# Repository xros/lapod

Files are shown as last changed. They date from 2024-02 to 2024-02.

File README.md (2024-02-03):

# LaPOD
LaPOD is a project to create a logic analyzer probe for the various [Rigol]
oscilloscopes that feature the logic analyzer connector. Not all scopes have
the connector exposed and not all scopes have the components needed on the
PCB. But for those that do, the LaPOD could be a cheap alternative to get
those probes.

## Scope support
Currently supported is the MSO5000 series, which feature a 50 pin IDC connector
and the DHO900, which features the same 50 pin connector, but is a bit more
narrow at the front. To cater for either needs or choice, there's two breakout
boards that feature either a full, but wider HDMI connector, or a mini HDMI
connector which makes the PCB as narrow as possible.

The idea is, to also get a 68 pin IDC connector added, but that requires
the knowledge of the pinout and someone that can validate and test the design.
The 68 pin IDC connector should have nearly the same signals however and would
fit the DS1074Z-S Plus for example.

The DS7000 and MSO8000 feature a PCI express 1x connector (34 pins), with an
unknown pinout, but the idea is that it could very much also support our pods.

## PODs
Currently, there are 3 pods available. The LMH7322 based pod, where two dual
channel chips supply 4 bits to the pod. The LMH7322 is the same chip used in
the official PLA2216 (MSO5000) and RPL1116 (DS1000Z) probes. It may also be
used on the RPL2316 (DS2000, DS7000 and MSO8000). The original probe needs 8
of these chips for 16 channels, and that brings the cost of the chips alone
up to around $75. Probably one of the reason of the high price.

Then there's also the LMH7324 based pod. Here a single quad channel chip is
used to supply the 4 bits to the pod. The LMH7324 is very closely related to
the LMH7322, but not identical. It is a little bit cheaper option and for some
signal scenarios even preferred to have the same chip handle 4 channels.

Finally, there is the SNV65LVDS based chip. It is a much cheaper chip that can
do logic signal detection, but at a very much more limited range. It also costs
considerably less. A true cheap alternative.

## Outputs
The schematics, PCB's gerbers etc are generated by the CI pipeline and can be
found under [releases](https://gitlab.com/riglol/lapod/-/releases) for tagged
builds. Tagging happens after verification however, so the release-candidates,
the files sent out to the board house for verification can be found under
[packages](https://gitlab.com/riglol/lapod/-/packages).

## Contact
Discussion about the development of these pods is held over on the
[EEVBlog forum].

[Rigol]: https://rigolna.com
[EEVBlog forum]: https://www.eevblog.com/forum/testgear/another-low-cost-la-probe-for-rigol-mso5000-by-oliv3r/

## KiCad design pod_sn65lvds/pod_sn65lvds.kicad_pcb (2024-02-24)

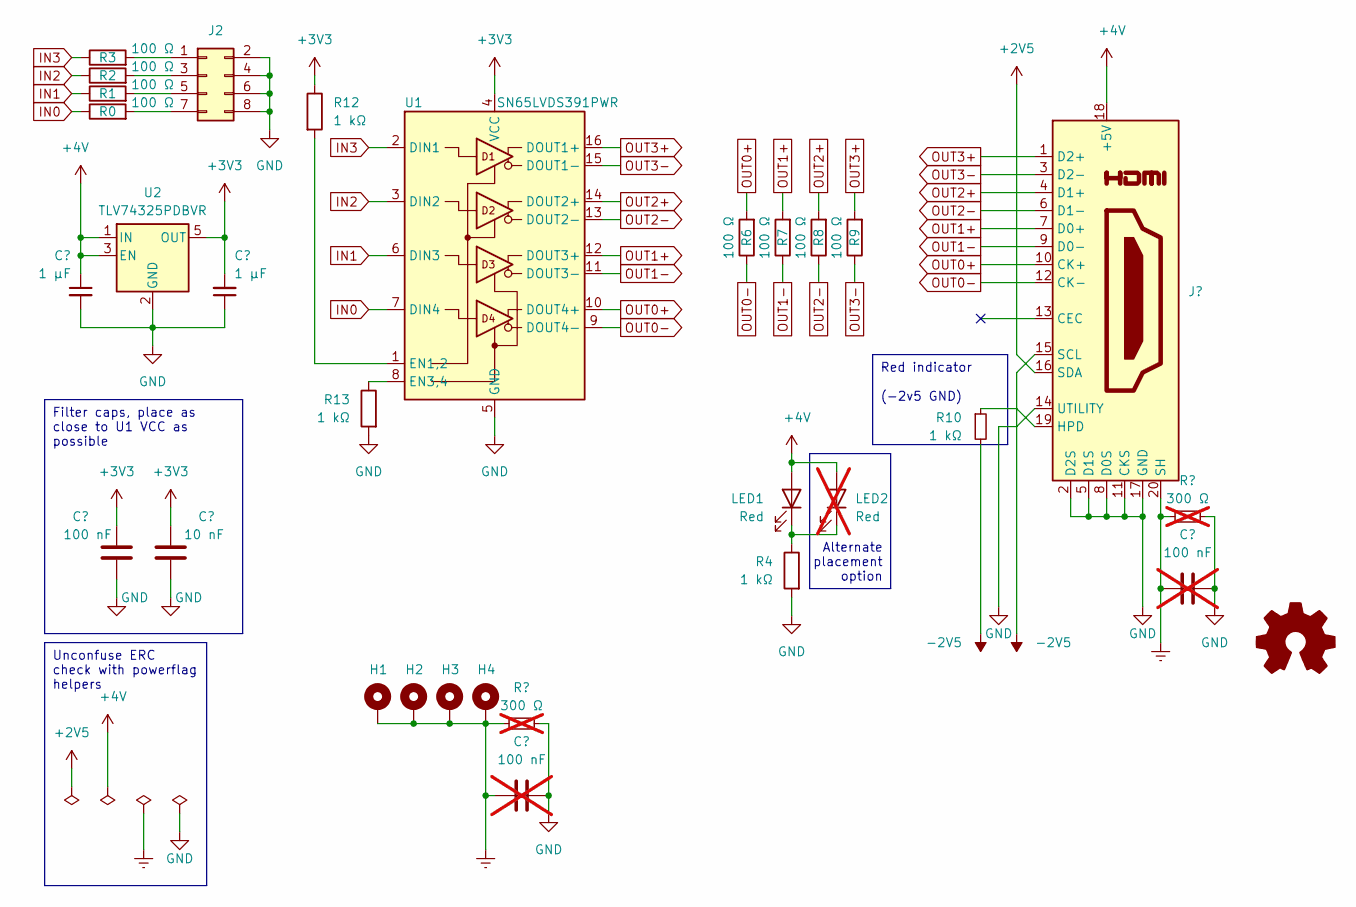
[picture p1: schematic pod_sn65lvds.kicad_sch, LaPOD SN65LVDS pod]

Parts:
C1, C4: 1 μF; C_0805_2012Metric_Pad1.18x1.45mm_HandSolder; tolerance 10%; LCSC C28323
C2: 100 nF; C_0805_2012Metric_Pad1.18x1.45mm_HandSolder; tolerance 10%; LCSC C49678
C3: 10 nF; C_0805_2012Metric_Pad1.18x1.45mm_HandSolder; tolerance 10%; LCSC C1710
C5, C6: 100 nF; C_0603_1608Metric_Pad1.08x0.95mm_HandSolder; tolerance 10%; LCSC C14663; not fitted
H1, H2, H3, H4: MountingHole_Pad; MountingHole_2.2mm_M2_Pad_Via
J1: HDMI_A; HDMI-SMD_HDMI-19PIN-043; LCSC C2858275
J2: Conn_02x04_Odd_Even; IDC-Header_2x04_P2.54mm_Horizontal; LCSC C9139
LED1: Red; LED_0805_2012Metric_Pad1.15x1.40mm_HandSolder; LCSC C84256
LED2: Red; LED_0805_2012Metric_Pad1.15x1.40mm_HandSolder; LCSC C84256; not fitted
R0, R1, R2, R3, R6, R7, R8, R9: 100 Ω; R_0805_2012Metric_Pad1.20x1.40mm_HandSolder; tolerance 1%; LCSC C17408
R4, R10, R12, R13: 1 kΩ; R_0805_2012Metric_Pad1.20x1.40mm_HandSolder; tolerance 1%; LCSC C17513
R5, R11: 300 Ω; R_0402_1005Metric_Pad0.72x0.64mm_HandSolder; tolerance 1%; LCSC C25102; not fitted
U1: SN65LVDS391PWR; TSSOP-16_4.4x5mm_P0.65mm; LCSC C354139
U2: TLV74325PDBVR; SOT-23-5_HandSoldering; LCSC C485154

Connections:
+2V5: J1.16 (SDA)
+3V3: C2.1, C3.1, C4.2, R12.1, U1.4 (VCC), U2.5 (OUT)
+4V: C1.1, J1.18 (+5V), LED1.2 (A), LED2.2 (A), U2.1 (IN), U2.3 (EN)
-2V5: J1.15 (SCL), R10.2
Earth: C5.2, C6.2, H1.1, H2.1, H3.1, H4.1, J1.20 (SH), R5.2, R11.2
GND: C1.2, C2.2, C3.2, C4.1, C5.1, C6.1, J1.2 (D2S), J1.5 (D1S), J1.8 (D0S), J1.11 (CKS), J1.14 (UTILITY), J1.17 (GND), J2.2, J2.4, J2.6, J2.8, R4.2, R5.1, R11.1, R13.2, U1.5 (GND), U2.2 (GND)
IN0: R0.1, U1.7 (DIN4)
IN1: R1.1, U1.6 (DIN3)
IN2: R2.1, U1.3 (DIN2)
IN3: R3.1, U1.2 (DIN1)
unnamed: J1.19 (HPD), R10.1
unnamed: J2.1, R3.2
unnamed: J2.3, R2.2
unnamed: J2.5, R1.2
unnamed: J2.7, R0.2
unnamed: LED1.1 (K), LED2.1 (K), R4.1
unnamed: R12.2, U1.1 (EN1,2)
unnamed: R13.1, U1.8 (EN3,4)
OUT0+: J1.10 (CK+), R6.2, U1.10 (DOUT4+)
OUT0-: J1.12 (CK-), R6.1, U1.9 (DOUT4-)
OUT1+: J1.7 (D0+), R7.2, U1.12 (DOUT3+)
OUT1-: J1.9 (D0-), R7.1, U1.11 (DOUT3-)
OUT2+: J1.4 (D1+), R8.2, U1.14 (DOUT2+)
OUT2-: J1.6 (D1-), R8.1, U1.13 (DOUT2-)
OUT3+: J1.1 (D2+), R9.2, U1.16 (DOUT1+)
OUT3-: J1.3 (D2-), R9.1, U1.15 (DOUT1-)

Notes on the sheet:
Alternate placement option
Red indicator (-2v5 GND)
Filter caps, place as close to U1 VCC as possible
Unconfuse ERC check with powerflag helpers

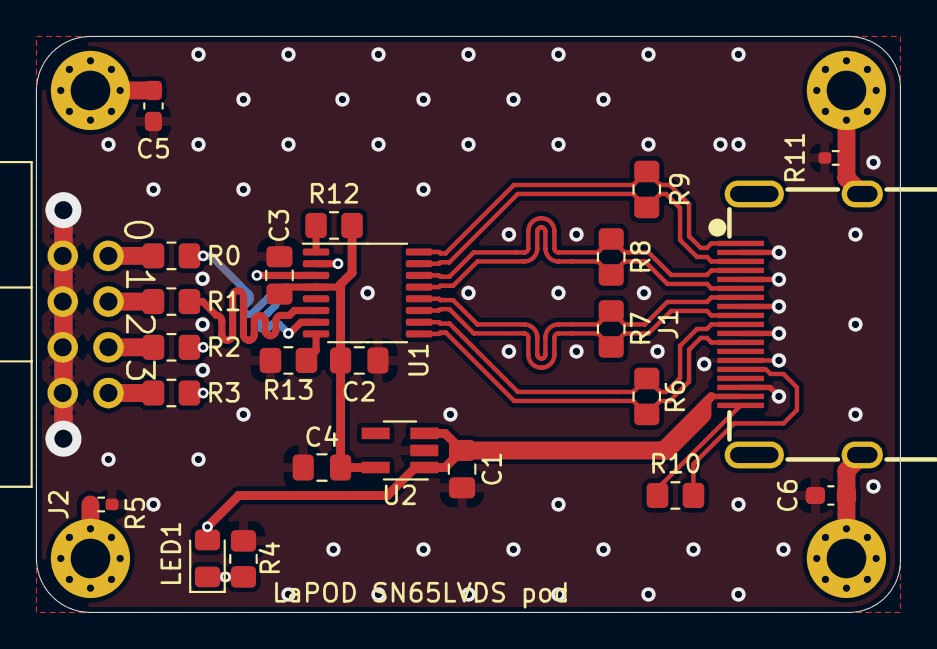
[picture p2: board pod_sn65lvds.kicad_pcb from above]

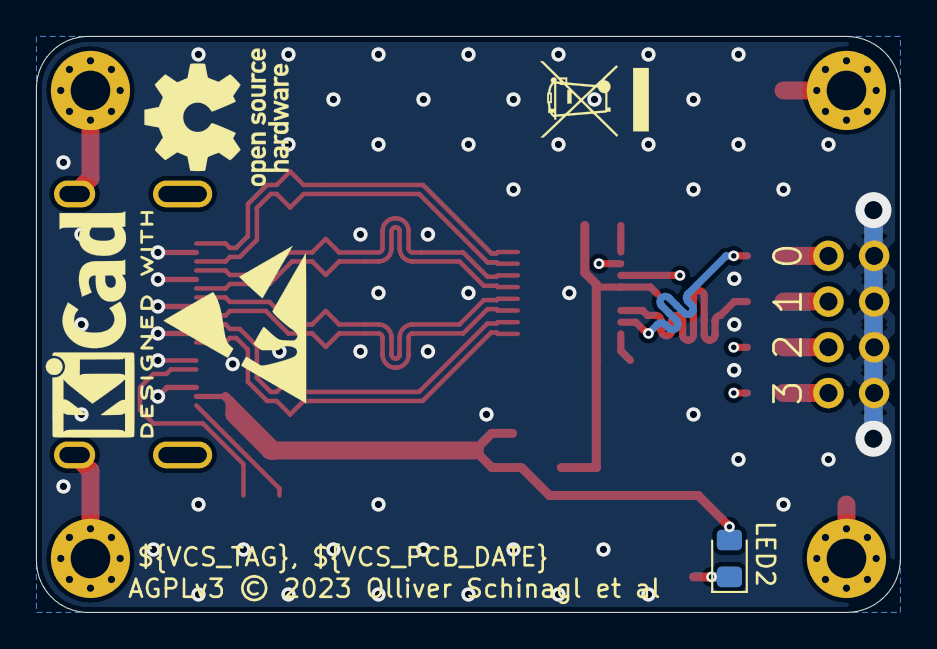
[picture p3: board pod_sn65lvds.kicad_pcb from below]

Board: 4 copper layers, 48.0 x 32.0 mm, 34 parts (5 on the bottom side), 25 nets.

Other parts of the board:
LG1: ESD-Logo_8.9x8mm_SilkScreen
LG2: KiCad-Logo2_5mm_SilkScreen
LG3: OSHW-Logo_7.5x8mm_SilkScreen
LG4: WEEE-Logo_4.2x6mm_SilkScreen

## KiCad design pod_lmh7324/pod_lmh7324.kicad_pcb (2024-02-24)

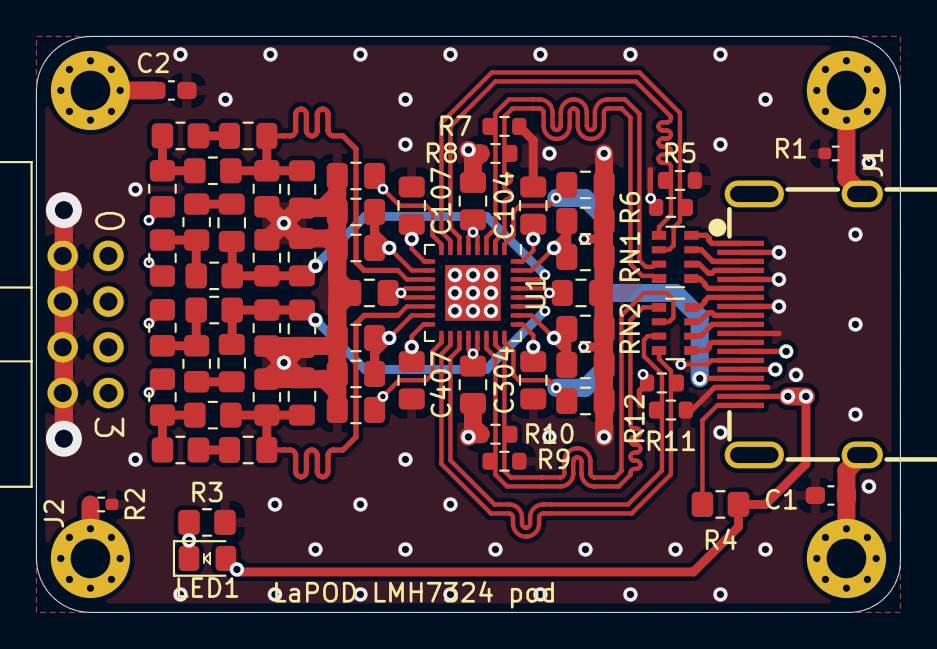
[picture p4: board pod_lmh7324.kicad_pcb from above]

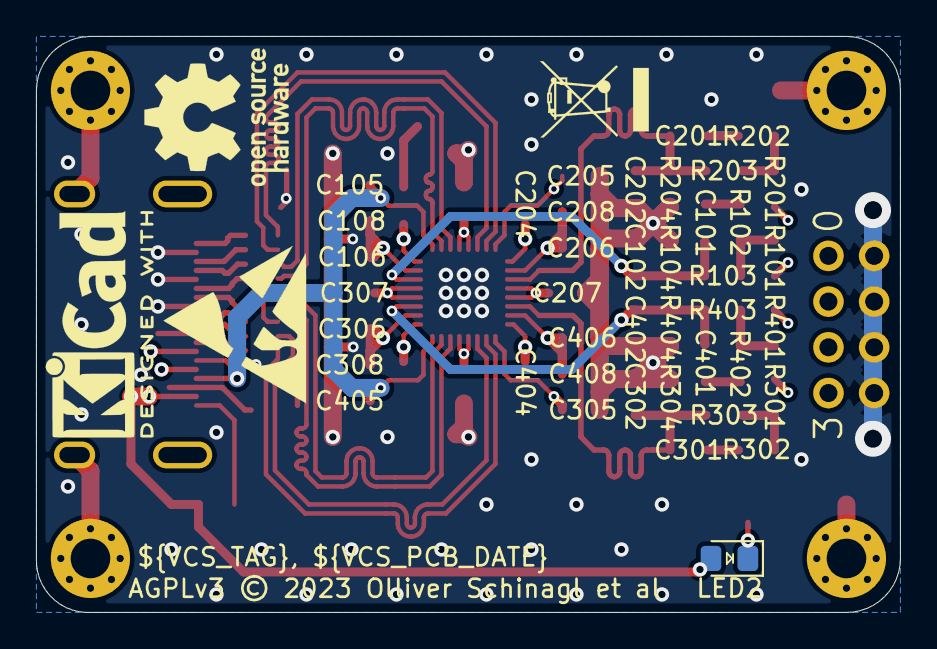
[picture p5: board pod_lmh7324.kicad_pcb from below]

Board: 4 copper layers, 48.0 x 32.0 mm, 73 parts (5 on the bottom side), 40 nets.

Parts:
C1, C2: 100 nF; C_0603_1608Metric_Pad1.08x0.95mm_HandSolder
C101, C201, C301, C401: 3.3 pF; C_0805_2012Metric_Pad1.18x1.45mm_HandSolder
C102, C202, C302, C402: 27 pF; C_0805_2012Metric_Pad1.18x1.45mm_HandSolder
C104, C105, C106, C107, C204, C205, C206, C207, C304, C305, C306, C307, C404, C405, C406, C407: 100 nF; C_0805_2012Metric_Pad1.18x1.45mm_HandSolder
C108, C208, C308, C408: 10 nF; C_0805_2012Metric_Pad1.18x1.45mm_HandSolder
H1, H2, H3, H4: MountingHole_Pad; MountingHole_2.2mm_M2_Pad_Via
J1: HDMI_A; HDMI-SMD_HDMI-19PIN-043
J2: Conn_02x04_Odd_Even; IDC-Header_2x04_P2.54mm_Horizontal
LED1, LED2: Blue; LED_0805_2012Metric_Pad1.15x1.40mm_HandSolder
LG1: ESD-Logo_8.9x8mm_SilkScreen
LG2: KiCad-Logo2_5mm_SilkScreen
LG3: OSHW-Logo_7.5x8mm_SilkScreen
LG4: WEEE-Logo_4.2x6mm_SilkScreen
R1, R2: 300 Ω; R_0402_1005Metric_Pad0.72x0.64mm_HandSolder
R3, R4: 1 kΩ; R_0805_2012Metric_Pad1.20x1.40mm_HandSolder
R5, R6, R7, R8, R9, R10, R11, R12: 220 Ω; R_0603_1608Metric
R101, R201, R301, R401: 300 Ω; R_0805_2012Metric_Pad1.20x1.40mm_HandSolder
R102, R202, R302, R402: 499 Ω; R_0805_2012Metric_Pad1.20x1.40mm_HandSolder
R103, R203, R303, R403: 90.9 kΩ; R_0805_2012Metric_Pad1.20x1.40mm_HandSolder
R104, R204, R304, R404: 10 kΩ; R_0805_2012Metric_Pad1.20x1.40mm_HandSolder
RN1, RN2: 49.9 Ω; R_Array_Convex_4x0603
U1: LMH7324; WQFN-32-1EP_5x5mm_P0.5mm_EP3.1x3.1mm

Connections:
+2V5: C105.1, C205.1, C305.1, C405.1, J1.16 (SDA), U1.1 (VCCO), U1.8 (VCCO), U1.17 (VCCO), U1.24 (VCCO)
+4V: C104.1, C204.1, C304.1, C404.1, J1.18 (+5V), LED1.2 (A), LED2.2 (A), R4.1, U1.9 (VCCI), U1.16 (VCCI), U1.25 (VCCI), U1.32 (VCCI)
-2V5: C107.1, C207.1, C307.1, C407.1, J1.15 (SCL), U1.4 (VEE), U1.5 (VEE), U1.12 (VEE), U1.13 (VEE), U1.20 (VEE), U1.21 (VEE), U1.28 (VEE), U1.29 (VEE)
Earth: C1.2, C2.2, H1.1, H2.1, H3.1, H4.1, J1.20 (SH), R1.2, R2.2
GND: C1.1, C2.1, C102.1, C104.2, C105.2, C106.1, C107.2, C108.1, C202.1, C204.2, C205.2, C206.1, C207.2, C208.1, C302.1, C304.2, C305.2, C306.1, C307.2, C308.1, C402.1, C404.2, C405.2, C406.1, C407.2, C408.1, J1.2 (D2S), J1.5 (D1S), J1.8 (D0S), J1.11 (CKS), J1.14 (UTILITY), J1.17 (GND), J2.2, J2.4, J2.6, J2.8, R1.1, R2.1, R3.2, R5.2, R6.2, R7.2, R8.2, R9.2, R10.2, R11.2, R12.2, R104.2, R204.2, R304.2, R404.2, U1.33 (VEE/EP)
IN0: J2.7, R301.2
IN1: J2.5, R401.2
IN2: J2.3, R101.2
IN3: J2.1, R201.2
unnamed: C101.1, R102.1
unnamed: C201.1, R202.1
unnamed: C301.1, R302.1
unnamed: C401.1, R402.1
unnamed: J1.10 (CK+), RN2.6 (R3.2)
unnamed: J1.12 (CK-), RN2.5 (R4.2)
unnamed: J1.7 (D0+), RN2.8 (R1.2)
unnamed: J1.9 (D0-), RN2.7 (R2.2)
unnamed: J1.4 (D1+), RN1.6 (R3.2)
unnamed: J1.6 (D1-), RN1.5 (R4.2)
unnamed: J1.1 (D2+), RN1.8 (R1.2)
unnamed: J1.3 (D2-), RN1.7 (R2.2)
unnamed: J1.19 (HPD), R4.2
unnamed: LED1.1 (K), LED2.1 (K), R3.1
unnamed: R101.1, R102.2, R103.1
unnamed: R201.1, R202.2, R203.1
unnamed: R301.1, R302.2, R303.1
unnamed: R401.1, R402.2, R403.1
unnamed: C101.2, C102.2, R103.2, R104.1, U1.30 (+)
unnamed: C201.2, C202.2, R203.2, R204.1, U1.11 (+)
unnamed: C301.2, C302.2, R303.2, R304.1, U1.14 (+)
unnamed: C401.2, C402.2, R403.2, R404.1, U1.27 (+)
OUT0+: R11.1, RN2.3 (R3.1), U1.19 (Q)
OUT0-: R12.1, RN2.4 (R4.1), U1.18 (~Q)
OUT1+: R9.1, RN2.1 (R1.1), U1.22 (Q)
OUT1-: R10.1, RN2.2 (R2.1), U1.23 (~Q)
OUT2+: R7.1, RN1.3 (R3.1), U1.3 (Q)
OUT2-: R8.1, RN1.4 (R4.1), U1.2 (~Q)
OUT3+: R5.1, RN1.1 (R1.1), U1.6 (Q)
OUT3-: R6.1, RN1.2 (R2.1), U1.7 (~Q)
VREF: C106.2, C108.2, C206.2, C208.2, C306.2, C308.2, C406.2, C408.2, J1.13 (CEC), U1.10 (-), U1.15 (-), U1.26 (-), U1.31 (-)

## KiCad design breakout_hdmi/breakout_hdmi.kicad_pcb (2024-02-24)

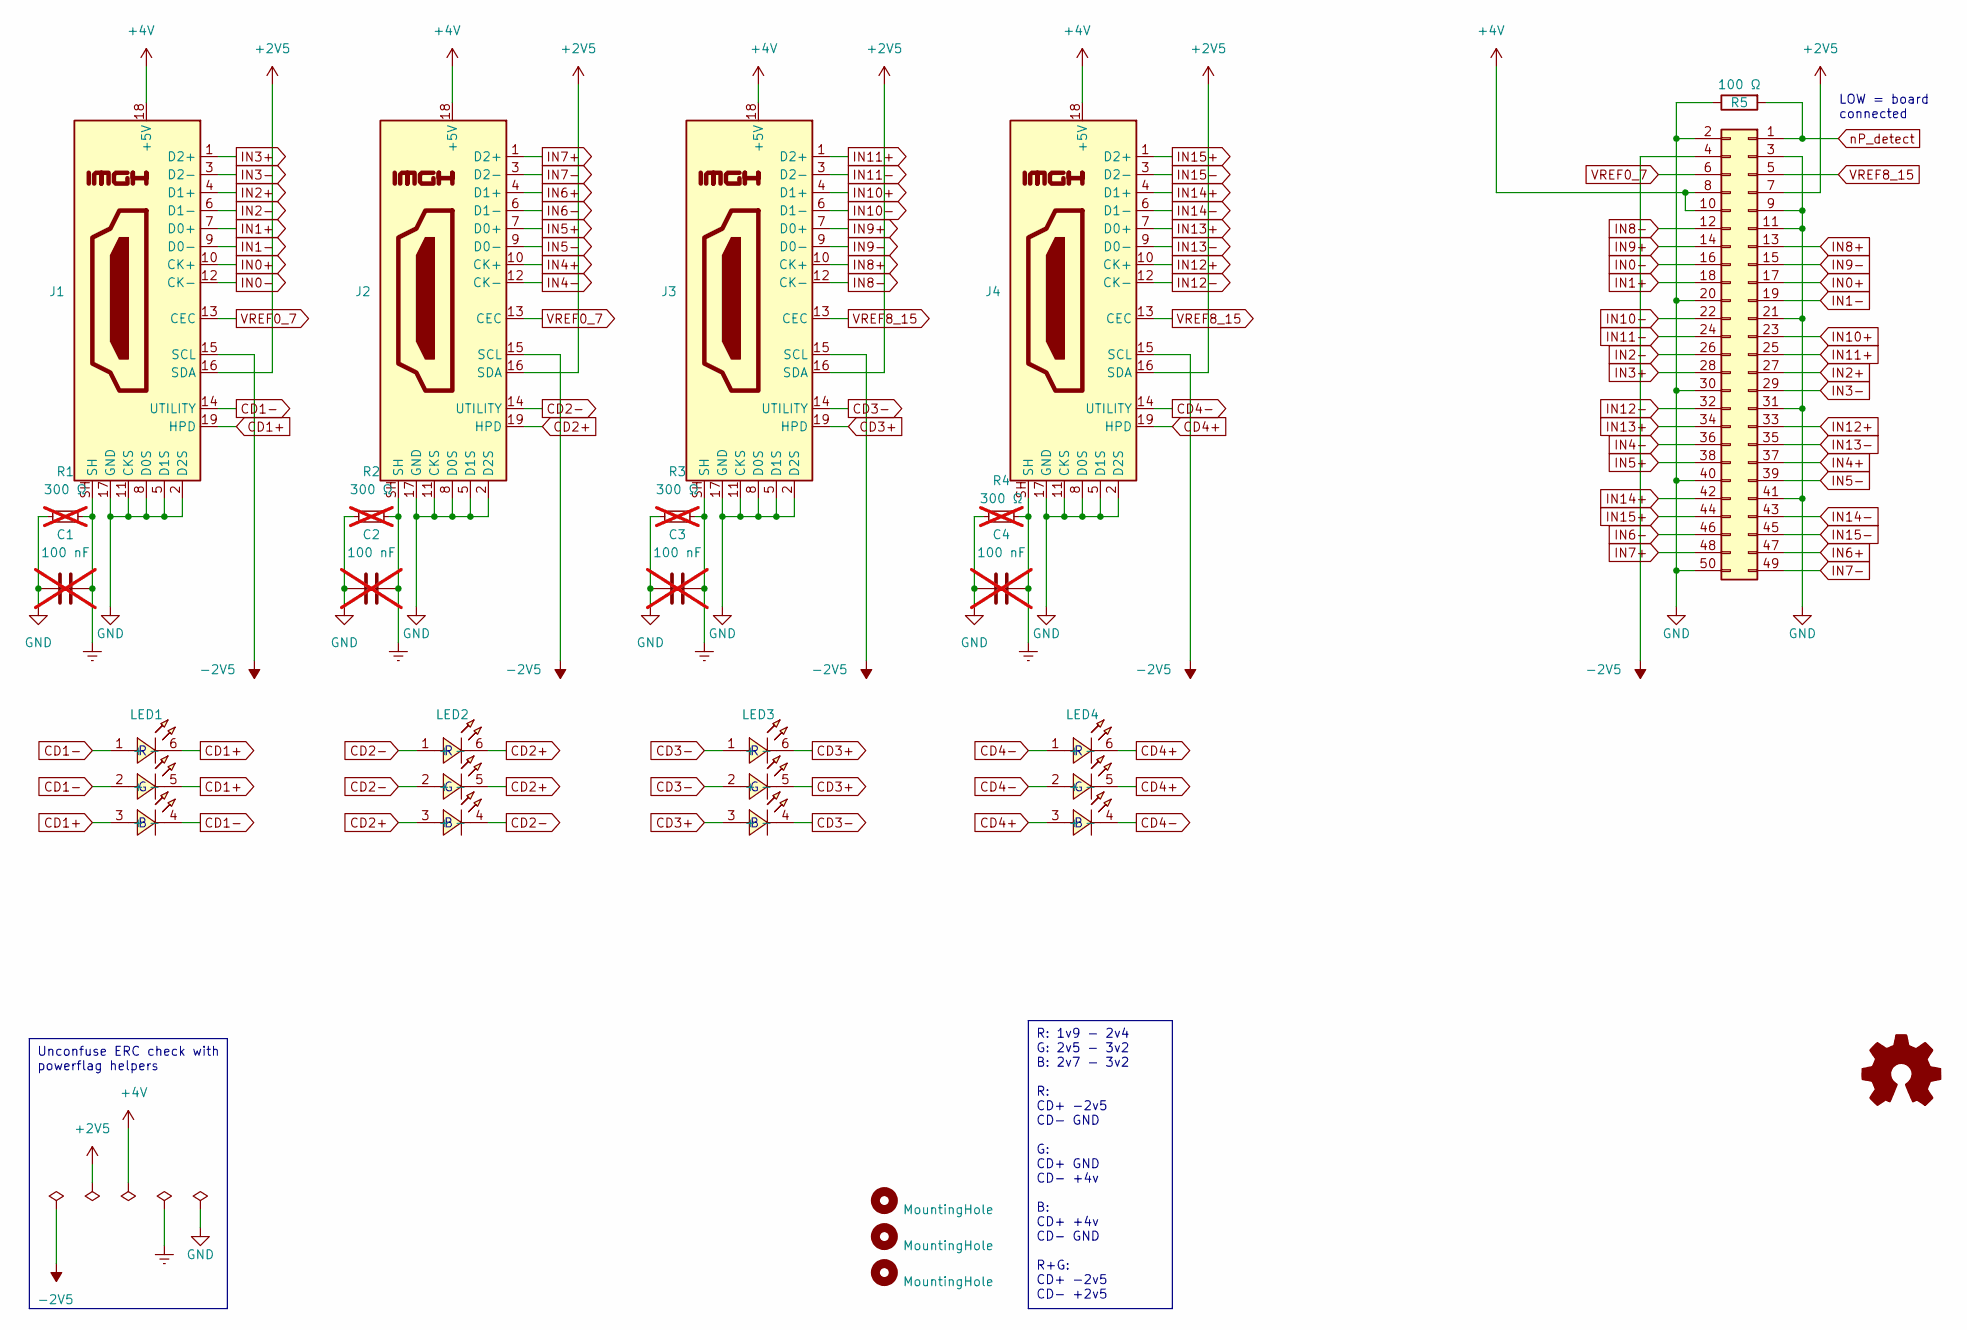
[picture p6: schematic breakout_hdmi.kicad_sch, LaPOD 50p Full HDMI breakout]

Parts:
C1, C2, C3, C4: 100 nF; C_0603_1608Metric_Pad1.08x0.95mm_HandSolder; tolerance 10%; voltage 50 V; LCSC C14663; not fitted
H1, H2, H3: MountingHole; MountingHole_2.2mm_M2_DIN965
J1, J2, J3, J4: HDMI_A; HDMI-SMD_HDMI-19PIN-043; LCSC C2858275
J5: Conn_02x25; IDC-Header_2x25_P2.54mm_Vertical_SMD; LCSC C350296
LED1, LED2, LED3, LED4: TC5050RGBF08-3CJH-AF53A; LED-SMD_6P-L5.0-W5.0-TL_TC5050RGBF08; LCSC C784540
R1, R2, R3, R4: 300 Ω; R_0402_1005Metric_Pad0.72x0.64mm_HandSolder; tolerance 1%; LCSC C25102; not fitted
R5: 100 Ω; R_0805_2012Metric_Pad1.20x1.40mm_HandSolder; tolerance 1%; LCSC C17408

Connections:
+2V5: J1.16 (SDA), J2.16 (SDA), J3.16 (SDA), J4.16 (SDA), J5.7
+4V: J1.18 (+5V), J2.18 (+5V), J3.18 (+5V), J4.18 (+5V), J5.8, J5.10
-2V5: J1.15 (SCL), J2.15 (SCL), J3.15 (SCL), J4.15 (SCL), J5.4
CD1+: J1.19 (HPD), LED1.3 (+), LED1.5 (-), LED1.6 (-)
CD1-: J1.14 (UTILITY), LED1.1 (+), LED1.2 (+), LED1.4 (-)
CD2+: J2.19 (HPD), LED2.3 (+), LED2.5 (-), LED2.6 (-)
CD2-: J2.14 (UTILITY), LED2.1 (+), LED2.2 (+), LED2.4 (-)
CD3+: J3.19 (HPD), LED3.3 (+), LED3.5 (-), LED3.6 (-)
CD3-: J3.14 (UTILITY), LED3.1 (+), LED3.2 (+), LED3.4 (-)
CD4+: J4.19 (HPD), LED4.3 (+), LED4.5 (-), LED4.6 (-)
CD4-: J4.14 (UTILITY), LED4.1 (+), LED4.2 (+), LED4.4 (-)
Earth: C1.2, C2.2, C3.2, C4.2, J1.SH, J2.SH, J3.SH, J4.SH, R1.2, R2.2, R3.2, R4.2
GND: C1.1, C2.1, C3.1, C4.1, J1.2 (D2S), J1.5 (D1S), J1.8 (D0S), J1.11 (CKS), J1.17 (GND), J2.2 (D2S), J2.5 (D1S), J2.8 (D0S), J2.11 (CKS), J2.17 (GND), J3.2 (D2S), J3.5 (D1S), J3.8 (D0S), J3.11 (CKS), J3.17 (GND), J4.2 (D2S), J4.5 (D1S), J4.8 (D0S), J4.11 (CKS), J4.17 (GND), J5.2, J5.3, J5.9, J5.11, J5.20, J5.21, J5.30, J5.31, J5.40, J5.41, J5.50, R1.1, R2.1, R3.1, R4.1, R5.1
IN0+: J1.10 (CK+), J5.17
IN0-: J1.12 (CK-), J5.16
IN1+: J1.7 (D0+), J5.18
IN1-: J1.9 (D0-), J5.19
IN2+: J1.4 (D1+), J5.27
IN2-: J1.6 (D1-), J5.26
IN3+: J1.1 (D2+), J5.28
IN3-: J1.3 (D2-), J5.29
IN4+: J2.10 (CK+), J5.37
IN4-: J2.12 (CK-), J5.36
IN5+: J2.7 (D0+), J5.38
IN5-: J2.9 (D0-), J5.39
IN6+: J2.4 (D1+), J5.47
IN6-: J2.6 (D1-), J5.46
IN7+: J2.1 (D2+), J5.48
IN7-: J2.3 (D2-), J5.49
IN8+: J3.10 (CK+), J5.13
IN8-: J3.12 (CK-), J5.12
IN9+: J3.7 (D0+), J5.14
IN9-: J3.9 (D0-), J5.15
IN10+: J3.4 (D1+), J5.23
IN10-: J3.6 (D1-), J5.22
IN11+: J3.1 (D2+), J5.25
IN11-: J3.3 (D2-), J5.24
IN12+: J4.10 (CK+), J5.33
IN12-: J4.12 (CK-), J5.32
IN13+: J4.7 (D0+), J5.34
IN13-: J4.9 (D0-), J5.35
IN14+: J4.4 (D1+), J5.42
IN14-: J4.6 (D1-), J5.43
IN15+: J4.1 (D2+), J5.44
IN15-: J4.3 (D2-), J5.45
VREF0_7: J1.13 (CEC), J2.13 (CEC), J5.6
VREF8_15: J3.13 (CEC), J4.13 (CEC), J5.5
nP_detect: J5.1, R5.2

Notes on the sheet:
R: 1v9 - 2v4 G: 2v5 - 3v2 B: 2v7 - 3v2 R: CD+ -2v5 CD- GND G: CD+ GND CD- +4v B: CD+ +4v CD- GND R+G: CD+ -2v5 CD- +2v5
Unconfuse ERC check with powerflag helpers
LOW = board connected

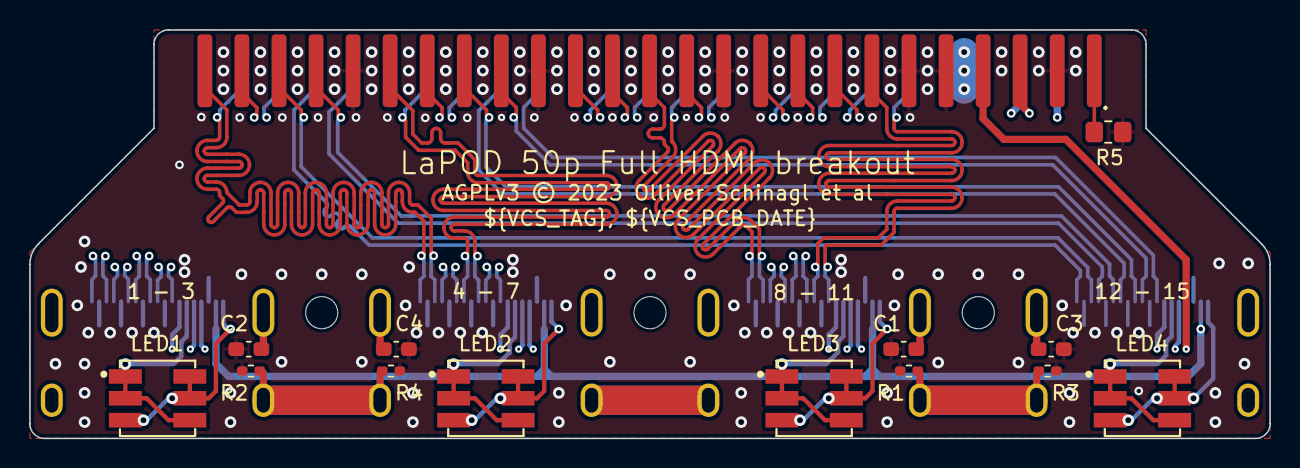
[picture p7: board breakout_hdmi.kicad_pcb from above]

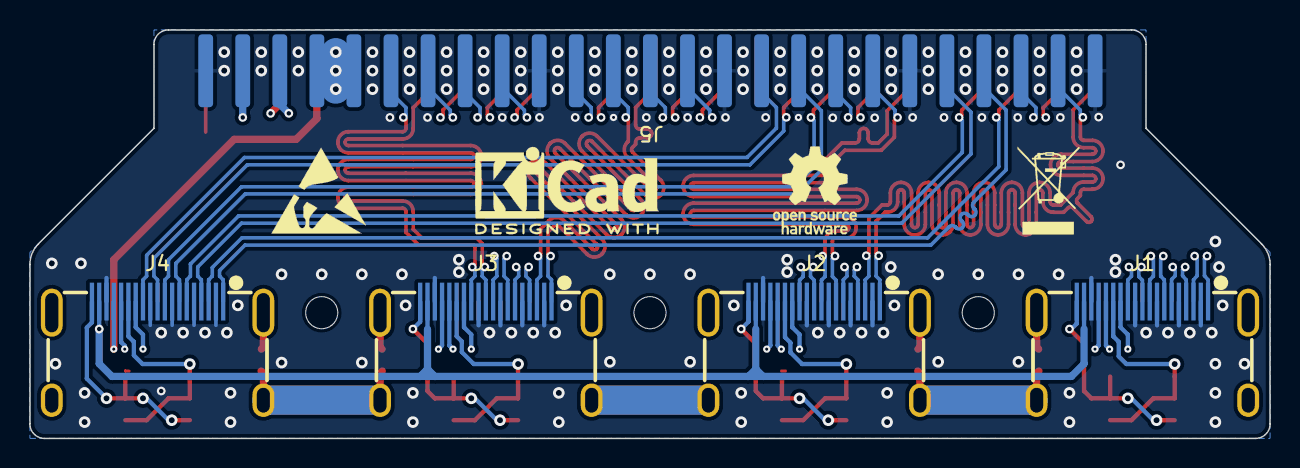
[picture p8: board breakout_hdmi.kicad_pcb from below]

Board: 4 copper layers, 85.0 x 28.0 mm, 25 parts (8 on the bottom side), 48 nets.

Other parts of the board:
LG1: OSHW-Logo_5.7x6mm_SilkScreen
LG2: KiCad-Logo2_5mm_SilkScreen
LG3: ESD-Logo_6.6x6mm_SilkScreen
LG4: WEEE-Logo_4.2x6mm_SilkScreen

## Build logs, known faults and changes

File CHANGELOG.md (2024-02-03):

# Changelog
All notable changes to this project will be documented in this file.

The format is based on [Keep a Changelog](https://keepachangelog.com/en/1.0.0/),
and this project adheres to [Semantic Versioning](https://semver.org/spec/v2.0.0.html).

## [v0.1.0] - 2024-02-03
### Added
- LaPOD logic analyzer pods and breakout boards

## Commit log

2024-01-23 gitignore: Ignore KiCad generated temporary files
2024-01-23 git: Enable LFS for PDF files
    No need to track datasheets.
2024-01-23 lapod: Add initial breakout_hdmi project
    This adds an empty project, so we can start setting up pipelines etc,
    and have a base to work with.
    [breakout_hdmi.kicad_pcb, breakout_hdmi.kicad_sch]
2024-01-23 CI: Use git compatible worksheet
    The built-in worksheet doesn't deal with git versions etc very well.
    While we could encode this information in the 'rev' box, it is too small.
    So instead of hacking around the shortcommings of the default worksheet,
    lets do our own.
    One problem remains, is that SHEETPATH and SHEETNAME are the two
    variables used to name a SHEET. Because they are used mutually
    exclusive, the 'hack' of putting both variables in place works
    reasonable, until it won't. Better would be for kicad to combine these
    variables in one name.
    Maybe we can make this worksheet the new default at some point.
2024-02-03 lapod: Add 50p full HDMI breakout board
    The first component of the LaPOD, the HDMI breakout board. Takes the 50
    pin Rigol connector, and converts it to 4 full HDMI ports.
    [breakout_hdmi.kicad_pcb, breakout_hdmi.kicad_sch]
2024-02-03 lapod: Add 50p mini HDMI breakout board
    Like the regular HDMI breakout board, this is the same board, but with
    mini-hdmi connectors, to make for a smaller width, fitting better in
    some scopes.
    [breakout_hdmi_mini.kicad_pcb, breakout_hdmi_mini.kicad_sch]
2024-02-03 lapod: Add LMH7322 based pod
    This commit adds the LMH7322 based pod. This pod is based on two dual
    opamps and uses two of these chips.
    This is the same chip the official rigol probe also uses. One of their
    pods contains 8 chips (4 on each side).
    As an option, only 1 LMH7322 can be used to only use a dual output, if
    heat and cost are an issue.
    [pod_lmh7322.kicad_pcb, pod_lmh7322.kicad_sch]
2024-02-03 lapod: Add LMH7324 based pod
    This commit adds the LMH7324 based pod. This pod is based on one quad
    opamp, potentially making the pod cheaper.
    Heat distribution should also be better, as there's more copper for just
    the one chip.
    [pod_lmh7324.kicad_pcb, pod_lmh7324.kicad_sch]
2024-02-03 lapod: Add SNV65LVDS based pod
    This commit adds the SNV65LVDS based pod. This pod is based on one quad
    opamp, but without the wide input range of the LMH732x parts, making it
    considerable cheaper.
    The BOM currently uses the SVN65LVCDS and TLV743P LDO, which limits the
    input range from 1v6 to 5v5 logic levels, which for most applications is
    perfectly fine for most applications, but alternative parts should fit
    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
    [pod_sn65lvds.kicad_pcb, pod_sn65lvds.kicad_sch]
2024-02-24 boyscout: Properly name GND zone in pcb
    No functional changes, this is just for consistency.
    [breakout_hdmi.kicad_pcb, breakout_hdmi_mini.kicad_pcb, pod_lmh7322.kicad_pcb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]
2024-02-24 fix: Replace SN65LVDS31D/SN65LVDS047W with SN65LVDS391PWR
    We accidentally used the incorrect LVDS comparator. The difference is
    subtle, but important.
    The symbol came from the KiCad default library, the rest of the part
    number from LCSC, but was simply the wrong one. 31D vs 391PWR. Subtle
    but important.
    Luckily, the footprint was almost the same, so no real changes where needed
    here.
    [pod_sn65lvds.kicad_pcb, pod_sn65lvds.kicad_sch]
2024-03-07 kibot: Switch to 1.6.5
    There's a cascading bug which break the pipeline currently. One is the
    fact that solder paste does not clear the underlying solder mask
    underneath it explicitly. However clearing it causes the DRC to complain
    where it says two layers are now clearing the same soldermask.
    Upgrading to the unreleased kibot 1.6.5 fixes this, but introduces a new
    problem with the kici render3d template, as the kibot changed its
    interface there.
    Upgrade to the 1.6.5 branch of kibot.

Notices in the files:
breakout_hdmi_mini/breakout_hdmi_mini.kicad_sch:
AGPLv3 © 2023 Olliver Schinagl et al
